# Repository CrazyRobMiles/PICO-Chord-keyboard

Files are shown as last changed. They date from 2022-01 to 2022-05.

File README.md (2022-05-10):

# PICO-Chord-keyboard
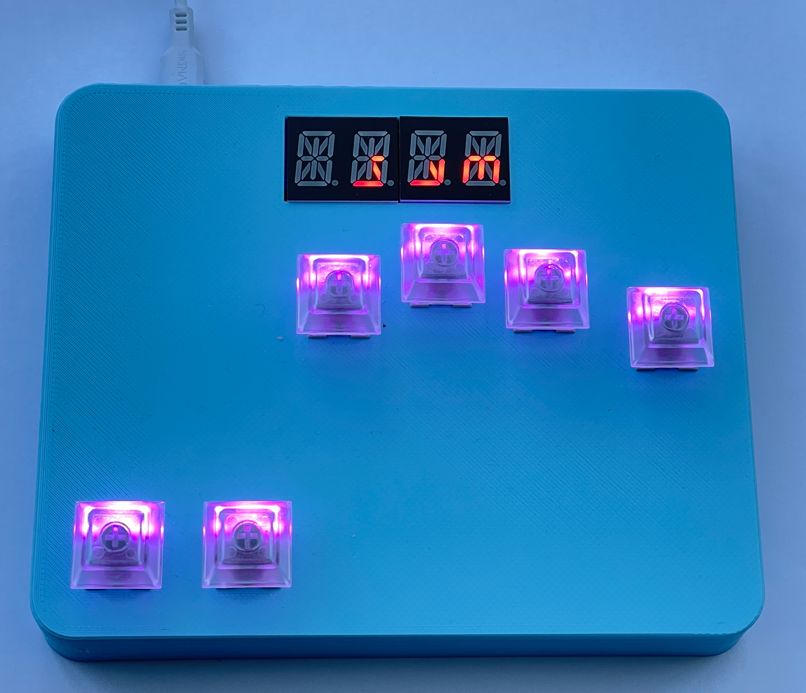
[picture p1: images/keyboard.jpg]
Image of keyboard

Designs and software for a chord keyboard controller. Created as the basis of an article for Hackspace magazine, issue 53. You can download the magazine [here](https://hackspace.raspberrypi.com/issues/53/pdf/download). The article is on page 68.
## Video
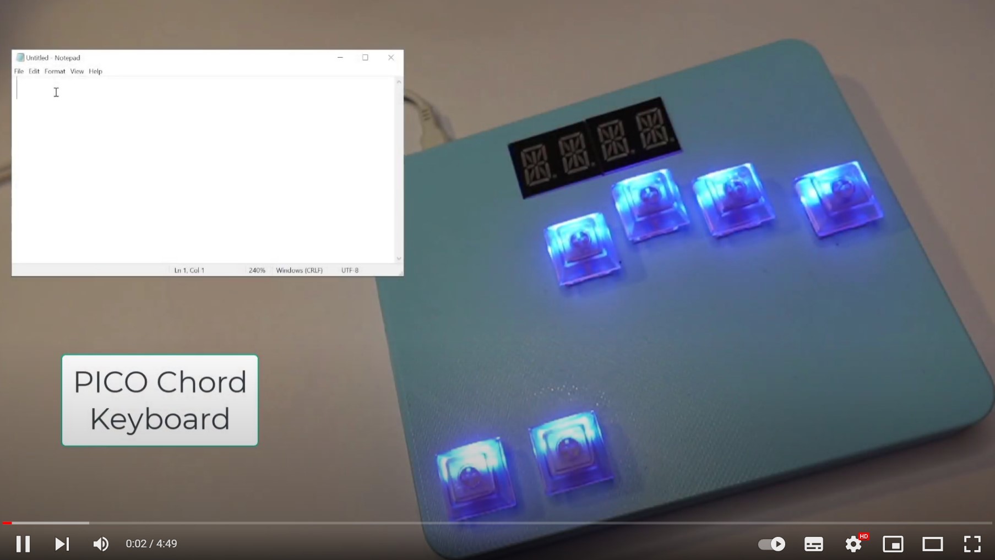
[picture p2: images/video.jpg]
YouTube Screenshot (https://youtu.be/ZogL7Nv60Xc)


To find out more about the device click on the image above to see a short video.

## Using the keyboard
The keyboard is implemented as a USB HID and can be used anywhere you would connect a USB keyboard. Characters are entered by pressing and releasing "chords". A full document and a keyboard map are available in the doc folder.
## History
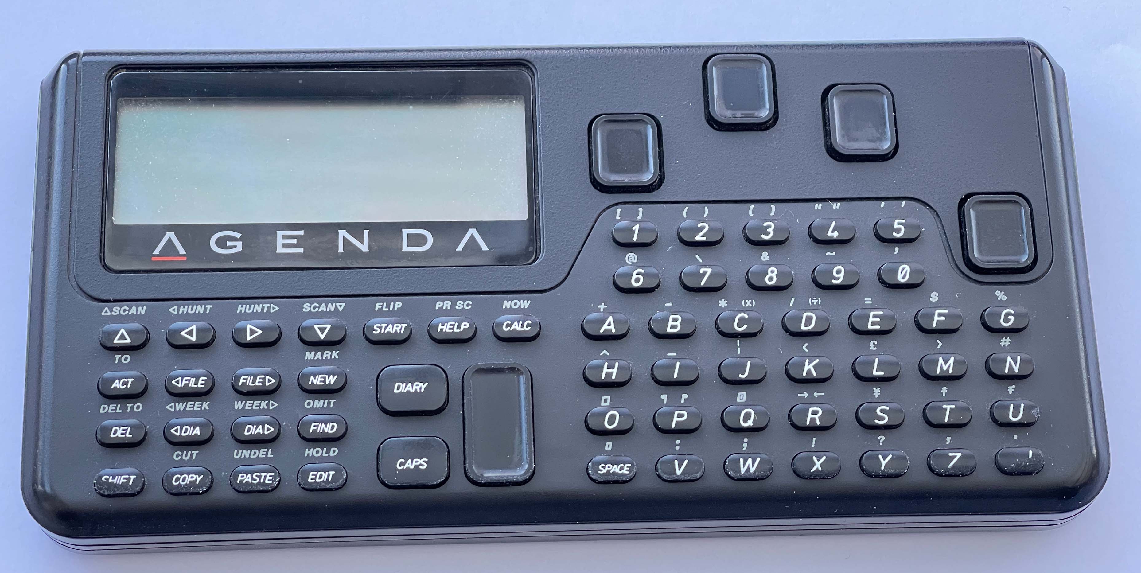
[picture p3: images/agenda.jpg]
Image of Microwriter Agenda

The keyboard is based on the Cykey chord design by Cy Enfield which was used as the basis of the Microwriter and Microwriter AgendA devices developed by him and Chris Rainey. You can find out more about these devices [here](http://www.computinghistory.org.uk/det/5794/Microwriter-MW4/), [here](https://www.microsoft.com/buxtoncollection/detail.aspx?id=5) and [here](https://mindmachine.co.uk/book/A/Inp-Outp/Microwriter01.html). 

If you want to buy an official Microwriter keyboard you can get one [here](https://sites.google.com/site/cykeybellaire/home). 
## Hardware
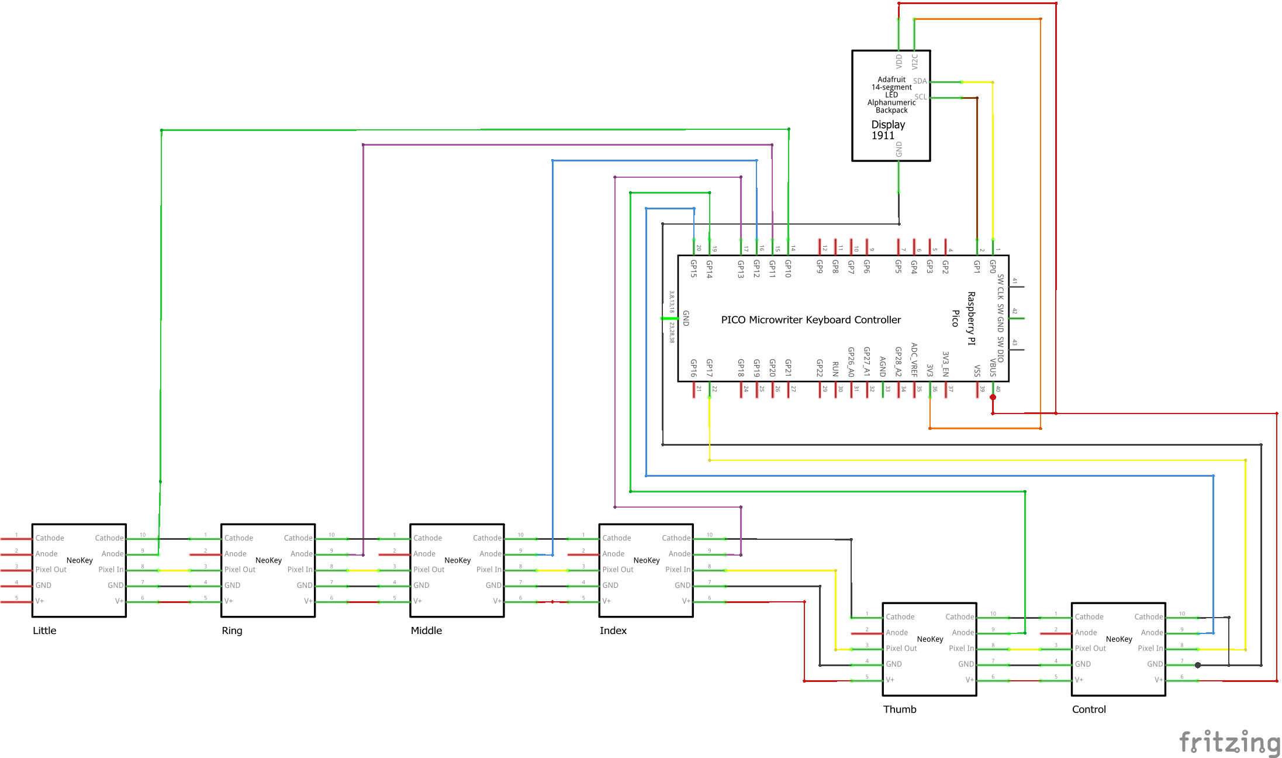
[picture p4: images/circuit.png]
Image of circuit


You will need the following hardware items:

* Six keyswitches. The Kailh Mechanical Keyboard Switches work well. You can get them in “clicky” or “non-clicky” form. 
* Six transparent keycaps. 
* Six Neokey Socket Breakouts from AdaFruit. These have a built-in neopixel that is used to show which keys to press for each letter. If you don’t want to use this part of the program you can just wire up the keys directly. 
* A four character alphanumeric display with an HT16K33 backpack. Search for "ht16k33 14 segment led". Make sure that you get the 14-segment device as this can display text.
* A Raspberry Pi PICO
* A micro-USB cable to link the PICO to the host
* Connecting wire (search for "30 AWG wire wrap") which needs a wire wrap tool (search for "wire wrap tool").
* A box. There is a 3D printable design, or you can put your keyboard in any box you fancy.
* Screws. You'll need some screws sized M2 4mm in length to fix things to the case (search for "laptop screws")
## Program installation
You must install Python 7 on your PICO device. Then copy the contents of the lib folder in this repository into the lib folder on your PICO. Finally copy the code.py file into root folder of your PICO.
## Left handed keyboard
The code now supports left handed operation. The connections are exactly the same. There is a new case top design for left handed use. 
```
version = "1.1"
# Make this false for a left-handed keyboard
RIGHT_HANDED = False
```
You make the above change to the code.py file (starting at line 17) to make the keyboard work in left handed mode. 
## Program development
You can use the Pymaker plugin for Visual Studio Code to develop this software. To save and run the program, copy the code.py file from this repository onto the root folder of your PICO. This should cause the program to restart.
## Case designs
There are case designs in the case folder. There is also a macro for FreeCAD which you can modify to produce cases with different key positions. 

Have Fun!
Rob Miles January 2022

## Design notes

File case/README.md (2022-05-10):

# Case Design

The case is created by a Python program that can be used to generate cases containing a large number of different elements. The program is called **BoxMacro.FCMacro** and runs inside the FreeCAD design tool which you can download from [here](https://www.freecadweb.org/downloads.php).

Each element in an enclosure is represented by one or more classes which are then automatically placed inside the base or the lid of the case. It is a bit of a pain to work with, I call it "3,000 lines of technical debt" but it does the job. 
## Left handed version
There is now an stl file for a left handed version of the case. I made this by just reflecting the right handed one using the [FreeCad mirror command](https://wiki.freecadweb.org/Part_Mirror).
## Moving keys up and down
Line 3181 in the current version of BoxMacro.
```
# adjust these offsets to move the keys up and down
    sw1=KeySwitchHole("Keyswitch1",xMargin=5,yMargin=10,slotYOffset=0)
    sw2=KeySwitchHole("Keyswitch2",xMargin=1,yMargin=2,slotYOffset=18)
    sw3=KeySwitchHole("Keyswitch3",xMargin=1,yMargin=2,slotYOffset=30)
    sw4=KeySwitchHole("Keyswitch4",xMargin=1,yMargin=2,slotYOffset=15)
    sw5=KeySwitchHole("Keyswitch5",xMargin=1,yMargin=2,slotYOffset=0)
    sw6=KeySwitchHole("Keyswitch6",xMargin=5,yMargin=5,slotYOffset=0)
```
If you want to move the keys up and down within their columns you just need to change the values of the offsets. For **keyswitch1** change the value of **yMargin**, for the other keys change the value of **slotYOffset**. This complication is due to the way that the autolayout positions items based on their sizes and margins. 
## Setting the size of the key areas
Line 3135 in the current version of BoxMacro.
```
#  Adjust these values to change the overall size of the key
    boardHeight = 21.0
    boardWidth = 21.0
# Adjust these to change the size of the key hole
    slotHeight=14.5
    slotWidth=14.5
```
If you want to change the size of the key positions (which will make the overall size of the box smaller) you can change the **boardheight** and **boardWidth** values. Be careful not to make them too small, as then the keys might crash into each other.

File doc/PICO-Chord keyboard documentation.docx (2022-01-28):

The keyboard can be used in place of a standard USB keyboard. You may find that a USB storage device appears when you connect the keyboard. You can ignore this.

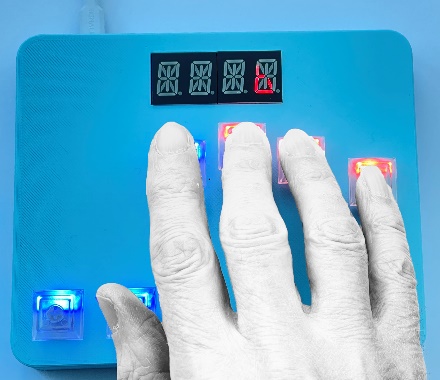
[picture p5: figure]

# Typing Text

You type on the keyboard by pressing down "chords". A chord is one or more keys. A key will turn red when it is pressed. A character is registered when you release one of the keys in the chord that describes it. Release all the chord keys for character before entering the next one. A map of all the chords is at the end of this document.

As an example, on the left the character "b" has been entered. The chord for "b" is the right hand three keys. When a letter has been registered the letter is sent as a keypress from the keyboard and appears on the alphanumeric keyboard. Text is entered using the five keys underneath the hand shown on the left. The far-left key is the control key.

# Control Key

The control key is used to change the mode of the keyboard. You use it by moving your thumb slightly left to press that key. If you press and release just the control key the keyboard will change from lower case to upper case text entry. The keys will change from blue to yellow. Press and release the control key again to return the lower-case text (at which point the keys will light up blue again).

# Commands

The control key can be used in conjunction with other letters to enter commands that change the mode of the keyboard and send cursor control commands from the keyboard. The chords for the commands are given at the end of this document. There are three kinds of command. Cursor control, keyboard mode and keyboard functions

## Cursor control

bak move the cursor left. This sends a keypress that moves the cursor one position left.

for move the cursor right. This sends a keypress that moves the cursor one position right

del backspace delete. This sends a keypress that deletes the character under the cursor and moves the cursor one space to the left.

## Keyboard mode

cap toggle the caps lock state. The keys turn either blue (caps) or yellow (lower case)

num enter numeric mode. The keys will turn green. You can enter numbers using the chords described in the Numbers section of the chord descriptions.

sym enter symbol mode. The keys will turn magenta. You can enter symbols using the chords described in the Symbols part of the chord descriptions.

text enter text mode. The keys will turn blue and the keyboard will be set to enter lower case text. You use this mode to exit from num or sym mode.

## Keyboard functions

help Type help. The keyboard will type out the keyboard chord descriptions. These can be loaded into a text editor for further reference. Stop the help output by holding down any key for a few seconds

game Play the learning game. The keyboard will display a character for you to enter on the keyboard. After a few seconds the keys for that character will be displayed in grey. The game continues until you get a character wrong. Note that the keys may change colour, to indicate that you need to change to the appropriate text entry mode before entering your key. At the end a score is displayed. You get more points if you enter characters before the help is displayed.

space

[ ] [ ] [ ] [ ]

[ ] [X]

,

[X] [ ] [X] [X]

[ ] [ ]

[X] [X] [X] [ ]

[ ] [ ]

A

[X] [X] [ ] [ ]

[ ] [ ]

B

[ ] [X] [X] [X]

[ ] [ ]

C

[ ] [X] [ ] [ ]

[ ] [X]

D

[X] [X] [ ] [ ]

[ ] [X]

E

[X] [ ] [ ] [ ]

[ ] [ ]

F

[X] [X] [X] [ ]

[ ] [X]

G

[ ] [ ] [X] [X]

[ ] [ ]

H

[ ] [ ] [ ] [X]

[ ] [X]

I

[X] [ ] [ ] [ ]

[ ] [X]

J

[ ] [ ] [X] [X]

[ ] [X]

K

[ ] [ ] [X] [ ]

[ ] [X]

L

[X] [ ] [ ] [X]

[ ] [X]

M

[X] [X] [X] [X]

[ ] [ ]

N

[ ] [X] [X] [ ]

[ ] [ ]

O

[ ] [X] [ ] [ ]

[ ] [ ]

P

[X] [X] [X] [X]

[ ] [X]

Q

[ ] [X] [ ] [X]

[ ] [ ]

R

[X] [ ] [X] [ ]

[ ] [X]

S

[ ] [ ] [X] [ ]

[ ] [ ]

T

[X] [ ] [X] [ ]

[ ] [ ]

U

[ ] [ ] [ ] [X]

[ ] [ ]

V

[X] [ ] [ ] [X]

[ ] [ ]

W

[X] [ ] [X] [X]

[ ] [X]

X

[ ] [X] [X] [X]

[ ] [X]

Y

[ ] [X] [X] [ ]

[ ] [X]

Z

[ ] [X] [ ] [X]

[ ] [X]

,

[X] [ ] [X] [X]

[ ] [ ]

[X] [X] [X] [ ]

[ ] [ ]

0

[ ] [X] [ ] [ ]

[ ] [ ]

1

[ ] [ ] [ ] [ ]

[ ] [X]

2

[X] [ ] [ ] [ ]

[ ] [X]

3

[X] [X] [ ] [ ]

[ ] [X]

4

[X] [X] [X] [ ]

[ ] [X]

5

[X] [X] [X] [X]

[ ] [X]

6

[ ] [ ] [ ] [X]

[ ] [ ]

7

[ ] [ ] [X] [X]

[ ] [ ]

8

[ ] [X] [X] [X]

[ ] [ ]

9

[X] [X] [X] [X]

[ ] [ ]

space

[ ] [ ] [ ] [ ]

[ ] [X]

!

[ ] [X] [X] [X]

[ ] [X]

[ ] [ ] [ ] [X]

[ ] [X]

$

[ ] [ ] [X] [ ]

[ ] [ ]

%

[ ] [X] [ ] [X]

[ ] [X]

&

[X] [ ] [X] [ ]

[ ] [X]

(

[X] [X] [ ] [ ]

[ ] [X]

)

[ ] [X] [X] [X]

[ ] [ ]

*

[X] [ ] [X] [ ]

[ ] [ ]

+

[X] [X] [X] [X]

[ ] [X]

,

[X] [ ] [X] [X]

[ ] [ ]

[ ] [X] [X] [ ]

[ ] [ ]

[X] [X] [X] [ ]

[ ] [ ]

/

[ ] [ ] [X] [ ]

[ ] [X]

:

[X] [ ] [X] [X]

[ ] [X]

;

[ ] [ ] [X] [X]

[ ] [X]

<

[X] [ ] [ ] [ ]

[ ] [X]

=

[X] [ ] [ ] [ ]

[ ] [ ]

>

[ ] [ ] [X] [X]

[ ] [ ]

?

[ ] [X] [X] [ ]

[ ] [X]

@

[X] [X] [ ] [ ]

[ ] [ ]

[

[ ] [X] [ ] [ ]

[ ] [X]

\

[X] [ ] [ ] [X]

[ ] [ ]

]

[ ] [X] [ ] [X]

[ ] [ ]

{

[X] [X] [X] [ ]

[ ] [X]

}

[X] [X] [X] [X]

[ ] [ ]

# Cursor

bak : Cursor left

[ ] [X] [X] [X]

[X] [ ]

for : Cursor right

[X] [X] [X] [ ]

[X] [ ]

del : Backspace

[X] [X] [ ] [ ]

[X] [ ]

# Mode

cap : Toggle CAPS lock

[ ] [ ] [ ] [ ]

[X] [ ]

num : Numeric (green)

[ ] [X] [X] [ ]

[X] [ ]

sym : Symbol (magenta)

[ ] [ ] [X] [ ]

[X] [ ]

text : Text (blue)

[X] [ ] [X] [ ]

[X] [ ]

# Function

game : Start the game

[ ] [ ] [X] [X]

[X] [ ]

help : Type key help

[ ] [ ] [ ] [X]

[X] [ ]

Rob Miles Version 1.0 January 2022

https://github.com/CrazyRobMiles/PICO-Chord-keyboard

PICO Chord Keyboard

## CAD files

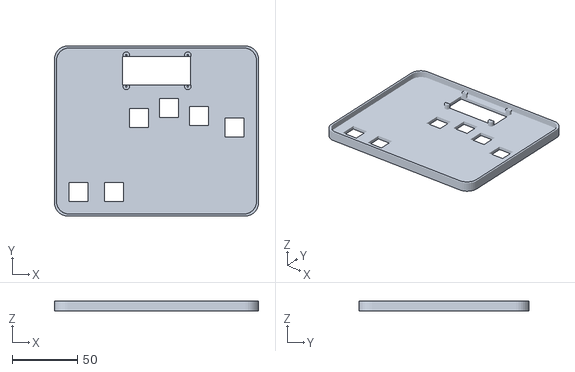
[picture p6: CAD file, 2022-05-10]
case/Left handed case top.stl
156.0 x 130.0 x 8.00

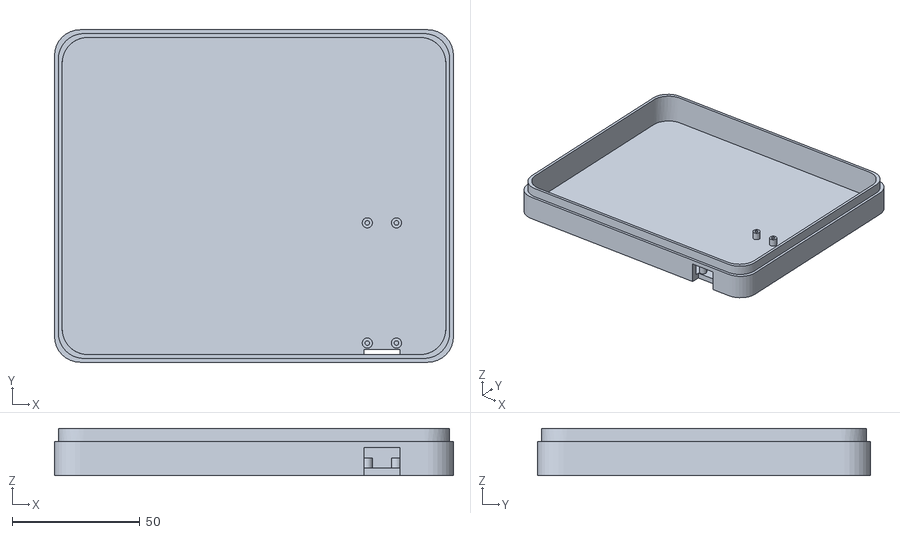
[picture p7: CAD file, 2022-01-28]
case/caseBottom.stl
156.0 x 130.0 x 18.5

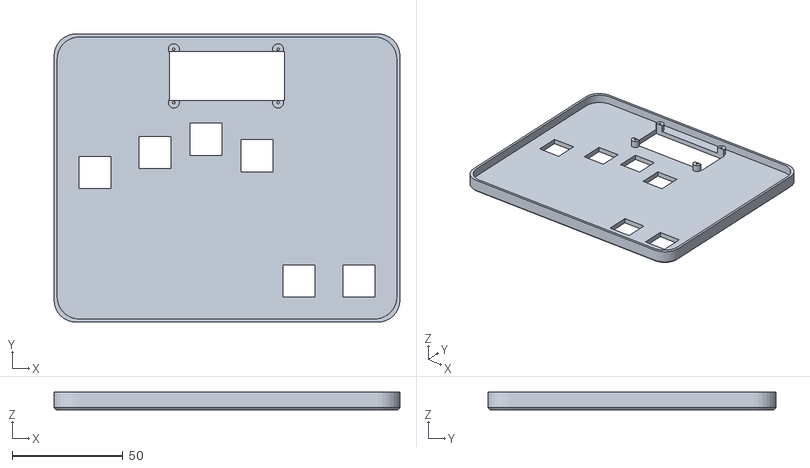
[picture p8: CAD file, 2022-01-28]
case/caseTop.stl
156.0 x 130.0 x 8.00

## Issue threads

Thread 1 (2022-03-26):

Hints on the macro for case generation?

codepope, 2022-03-26:
Could there be some hints on how the macro works?

Background: I was going to print the default STL but it's mm too wide on the edges for my Adventurer 3. So I settled down to figure out how the macro assembles things but I couldn't figure out how the components worked together to get the overall size (which I think comes as a function of the the keylayout and insets). So I would love to see some notes on the dependencies inside there.... (before I panic and look for a bigger printer :) )

CrazyRobMiles, 2022-04-06:
Hi. Good point. I've added extra details about changing the size and position of the keys.

codepope, 2022-04-06:
Thanks! Will give the info a run tonight!

codepope, 2022-04-06:
Actually, already have and sized the box down to something I can print. So that's great.

Closed 2022-04-06.

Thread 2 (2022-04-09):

HT16K33 power issue

codepope, 2022-04-09:
Built out the pico and display as per the schematic and loaded a test app up on it with latest release CP. Reported no device at 0x70. After a long tear down and comparison with a Feather based config I'd put together, I eventually found the Adafruit CP docs for the HT16K33 breakout and they don't have the VDD(schematic)/VCC(on board) running to the Pico VBus. Instead, VDD/VCC and Vi2C are both wired to the 3.3v pin on the Pico. I repeated the process on my rig and the display turned up on 0x70 and worked at full brightness (only connecting VDD/VCC gives half brightness). Don't know if its a variation in the break out boards, bit with this being a fresh bits build, thought you might want to know. (Now onwards to keyswitches)

CrazyRobMiles, 2022-04-14:
Thanks for the info. I've not seen this problem before. I wanted to power the keys and their lights directly from the usb power input and not put any load on the 3.3 regulator on the PICO (which I think is current limited). It might be that your usb  connection is slightly current limited (some of the ones on my PC are very bad for this) or you have a thin usb cable (I've found some cables are very bad for this). Powering the keys from the 3.3 supply would reduce the total load on the input a bit and make a marginal power supply work. I'd say if it works, go for it. FYI, according to my little usb current monitor the device takes 135ma or so.

CrazyRobMiles, 2022-05-01:
I've had a proper think about this and I think I was wrong about the cause of the problem. It is much more likely to be an issue with the way that NeoPixels need a signal level of at least 60% of the power voltage for the signal to be detected.

A PCIO is a 3.3 volt device and so the high level of the control signal going into the NeoPixel will be 3.3 volts. If the supply voltage gets close to or slightly above 5 volts the NeoPixel  will not see any signal values coming in because 3.3 is less than 60% of the supply voltage. However, if you drop the supply voltage to 3.3 volts (which you are doing) the signal voltage is now well over 60% and it all works. I've found that while some pixels can handle less than 60% of signal voltage some (notably Adafruit branded ones) don't. I'm presently running a 64 pixel panel (at 0.3 brightness) of the 3.3v supply on a PICO and it seems to be working fine at the moment.

codepope, 2022-05-01:
That makes sense - and deffo something for new builds to keep an eye open for. (Goes and gets a 4.9v psu :) )

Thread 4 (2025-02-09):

Unable to read .mpy files

robwolf13, 2025-02-09:
Hi

So I have been trying to get this project working but having an issue access the libraries that are in the .mpy format.

I have cloned the git and uploaded it to the raspberry pi pico W. When I try to run the code it saying

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

When I try to open it in Thonny it says the file is not supported.

When I open it with a text editor says the encoding is wrong and there are invalid characters.

System info: Ubuntu 22.04
Thonny 4.1.6

What I need to know is what encoding I might need to open the library files?

CrazyRobMiles, 2025-02-10:
Hi. Sorry to hear you are having problems. The issue might be that the library files on the GitHub for this project are for Version 7 of Circuit Python. If you've installed Version 9 on your PICO W you will get compatibility issues. I've copied the libraries that you need into a v9lib folder on the repository. Try those and let me know how you get on.

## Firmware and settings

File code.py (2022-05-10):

import board
import busio
import time
from digitalio import DigitalInOut, Direction, Pull
import neopixel
from adafruit_debouncer import Debouncer
import usb_hid
from adafruit_hid.keyboard import Keyboard
# Import the keyboard layout description
from adafruit_hid.keyboard_layout_uk import KeyboardLayoutUK

from adafruit_hid.keycode import Keycode
from adafruit_ht16k33 import segments

version = "1.1"
# Make this false for a left-handed keyboard
RIGHT_HANDED = True

class Col:
    
    RED = (255, 0, 0)
    YELLOW = (255, 150, 0)
    GREEN = (0, 255, 0)
    CYAN = (0, 255, 255)
    BLUE = (0, 0, 255)
    MAGENTA = (255, 0, 255)
    WHITE = (255, 255, 255)
    BLACK = (0, 0, 0)
    GREY = (10, 10, 10)
    VIOLET = (127,0,155)
    INDIGO = (75,0,130)
    ORANGE = (255,165,0)
       
    values=(RED, GREEN, BLUE, YELLOW, MAGENTA, CYAN, GREY, WHITE)
    
    names={ RED:"Red", YELLOW:"Yellow", GREEN:"Green", CYAN:"Cyan",
            BLUE:"Blue", MAGENTA:"Magenta", WHITE:"White",BLACK:"Black",
            GREY:"Grey",VIOLET:"Violet",INDIGO:"Indigo",ORANGE:"Orange"}

class Switch:
    def __init__(self, pin, pixel, bit)  :
        self.pin = pin
        self.pixel = pixel
        self.bit = bit

class Key():
    def __init__(self, keyboard, switch): 
        self.keyboard = keyboard
        self.pixel = switch.pixel
        self.bit = switch.bit
        # make a digital io from the pin
        io = DigitalInOut(switch.pin)
        # add a pullup
        io.pull = Pull.UP
        # create the key debouncer
        self.debounce = Debouncer(io,interval=0.01)
        self.debounce.update()
        self.pressed = not self.debounce.value
        self.down_col=Col.RED
        self.up_col=Col.BLUE
        self.guide_key_col=Col.GREY
        self.guide_key=False

    def update(self):
        debounce = self.debounce
        debounce.update()
        if debounce.fell:
            self.key_down()
        if debounce.rose:
            self.key_up()
        if(self.pressed):
            col = self.down_col
        else:
            if self.guide_key:
                col = self.guide_key_col
            else:
                col = self.up_col
        self.set_col(col)
            
    def set_col(self,col):
        keyboard.pixels[self.pixel] = col
            
    def key_down(self):
        keyboard = self.keyboard
        self.pressed = True
        if keyboard.character_bits == 0:
            # this is the first press of a new character
            keyboard.assembling_bits = True
        keyboard.character_bits = keyboard.character_bits + self.bit
    
    def key_up(self):
        keyboard = self.keyboard
        self.pressed = False
        # get the current bits value
        bits = keyboard.character_bits
        # clear this bit from the keyboard
        keyboard.character_bits = keyboard.character_bits - self.bit
        if keyboard.assembling_bits:
            # This is the first key up - we have a char
            keyboard.assembling_bits = False
            keyboard.got_bits(bits)
            
class Processor:

    def __init__(self, keyboard): 
        self.keys = keyboard

class TextProcessor(Processor):

    def __init__(self, keyboard): 
        super(TextProcessor,self).__init__(keyboard)

    def start(self):
        self.keys.display_text("")
        self.keys.start_lower_case_text()

    def key_pressed(self,key):
        print("Key pressed text:", key)
        self.keys.display_text(key)
        self.keys.usb_layout.write(key)
        
    def update(self):
        pass

class HelpProcessor(Processor):

    def __init__(self, keyboard): 
        super(HelpProcessor,self).__init__(keyboard)

    def start(self):
        print("Start help")
        self.keys.set_keyboard_state(PicoChord.LOWER_CASE_KEYS)
        self.keys.clear_all_keys()
        self.keys.pixels.show()        
        self.keys.scroll_text("Printing help. Hold any key to stop")
        self.mode=PicoChord.HELP_MODE
        time.sleep(2.0) 
        self.text_waiting_for_clear_keys = True
        self.test_count=0
        
    def key_pressed(self,key):
        print("Key pressed help:", key)

    def print_stop_check(self):
        self.keys.update_keys()
        if self.keys.character_bits != 0:
            return True

    def update(self):
        if self.text_waiting_for_clear_keys:
            if self.keys.character_bits == 0:
                # all the keys are up, we can start the output
                self.game_waiting_for_clear_keys = False
                self.keys.print_keys()
                self.keys.scroll_text("Help complete")
                self.keys.set_keyboard_state(PicoChord.LOWER_CASE_KEYS)
                self.keys.clear_all_keys()
                self.keys.clear_keyboard_guides()
                self.keys.start_mode(PicoChord.TEXT_MODE)
                self.keys.pixels.show()
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

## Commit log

2022-01-28 First full release
    [caseBottom.stl, caseTop.stl]
2022-04-06 Added details of case customisation
2022-04-06 Reverted to original case size
2022-05-10 Added left handed operation
    [Left handed case top.stl]
